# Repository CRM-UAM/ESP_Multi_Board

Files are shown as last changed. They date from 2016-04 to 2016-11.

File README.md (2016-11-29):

# ESP_Multi_Board (En constucción)
Diseño de una nueva placa basada en el módulo ESP8266 con conextividad WIFI y extensión para soportar dos motores DC, 8 GPIO digitales (MCP23008), 12 entradas Análogicas (MAX11605EEE+), giroscopio y acelerómetro (MPU6050)


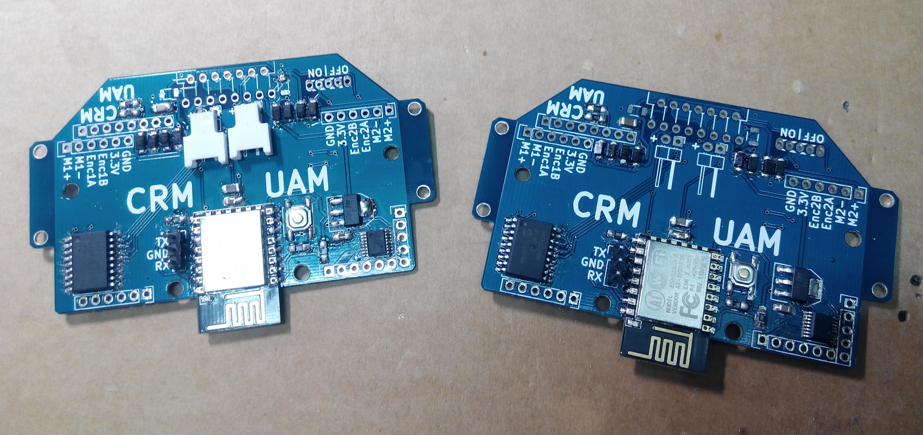
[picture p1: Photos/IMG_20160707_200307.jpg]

_ESP Multi Boards_

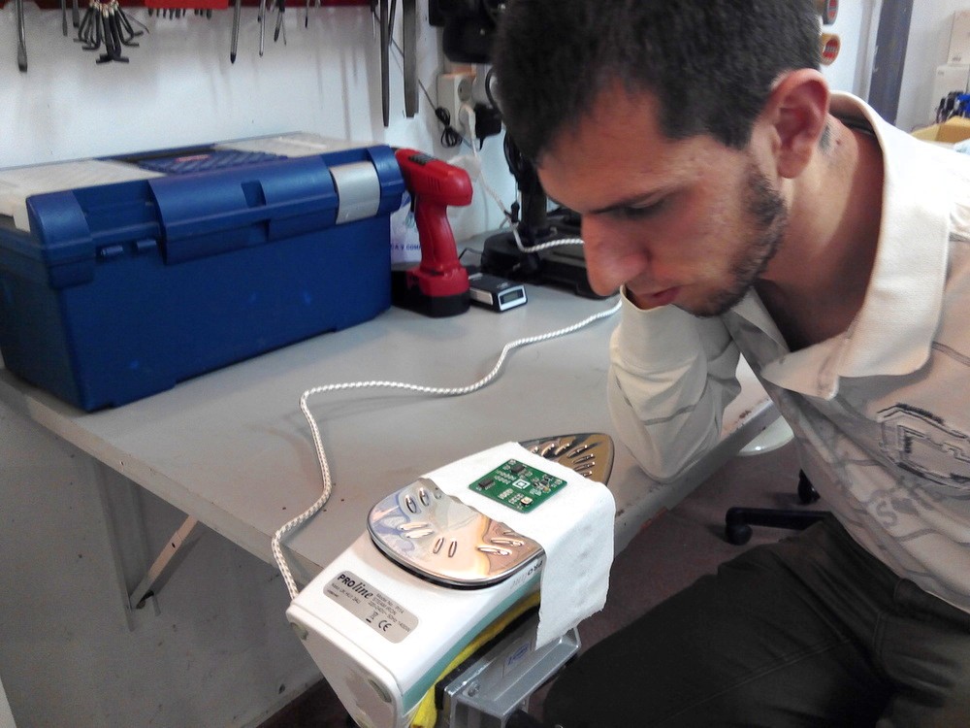
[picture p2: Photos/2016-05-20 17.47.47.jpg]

_SMD boards can be soldered using an iron and low-temp solder paste (a.k.a. "¡soldadas con [el método de la plancha!](https://www.youtube.com/watch?v=2VqYg4uM7OA)")_

##Librerias
+ [Arduino IDE for ESP8266](http://www.arduinesp.com/ "ArduinESP")
+ [MCP23008 lib for Arduino](https://github.com/adafruit/Adafruit-MCP23008-library "MCP23008 library")

IR values
cm - val
0 - 216
2 - 130
3 - 92
4 - 73
5 - 53
6 - 40
7 - 34
10 - 21

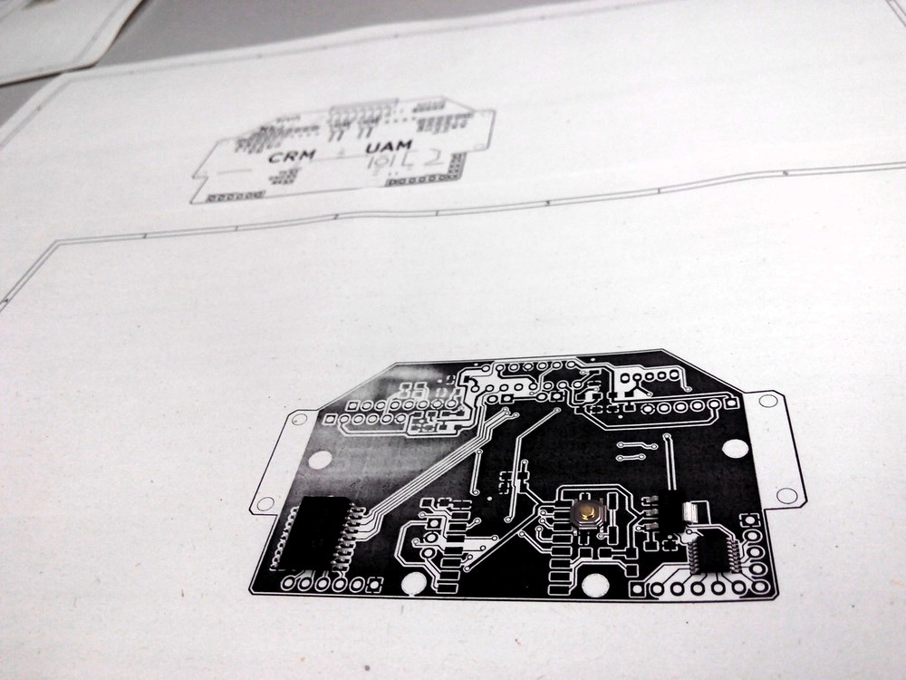
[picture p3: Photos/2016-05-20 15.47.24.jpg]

_Testing the components before sending the PCB out for manufacture_

Authors
--
**Víctor Uceda & Carlos García**  
Club de Robótica-Mecatrónica, Universidad Autónoma de Madrid (CRM-UAM)  
<http://crm.ii.uam.es>  

License
--
License: **Attribution - Share Alike - Creative Commons (<http://creativecommons.org/licenses/by-sa/4.0/>)**  

Disclaimer  
--
This hardware/software is provided "as is", and you use the hardware/software at your own risk. Under no circumstances shall any author be liable for direct, indirect, special, incidental, or consequential damages resulting from the use, misuse, or inability to use this hardware/software, even if the authors have been advised of the possibility of such damages.

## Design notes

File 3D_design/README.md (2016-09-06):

IR sensor holder for maze-solving with ESP-Multi-Board
=

Holds a *SFH4545* (photo-diode) infrared emmiter and a *TEFT4300* (photo-transistor) receiver

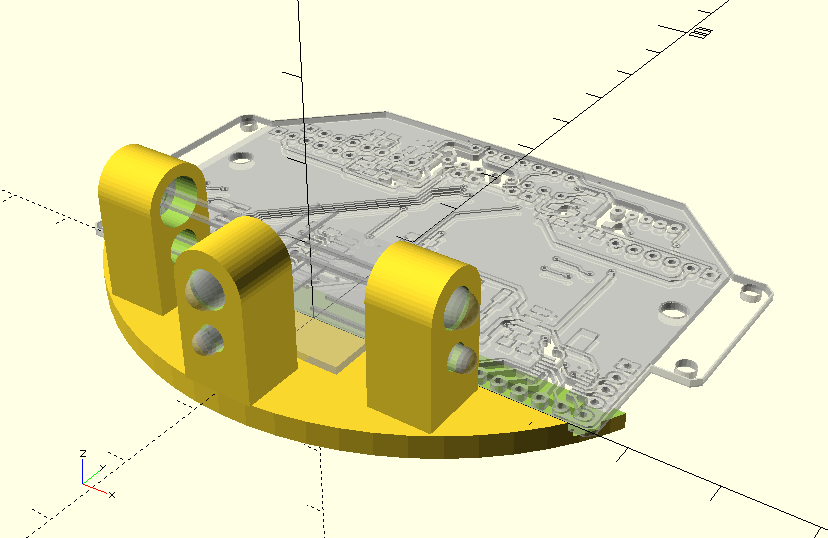
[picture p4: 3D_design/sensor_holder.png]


License: CC-BY-SA 4.0 (Attribution-ShareAlike 4.0 International, <http://creativecommons.org/licenses/by-sa/4.0/>)
Designed with <http://www.openscad.org/>

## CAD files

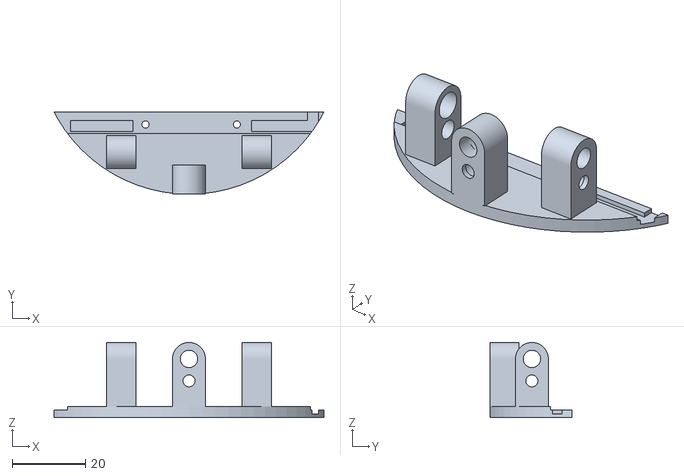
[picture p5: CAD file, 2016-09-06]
3D_design/sensor_holder.stl
73.7 x 22.5 x 20.5

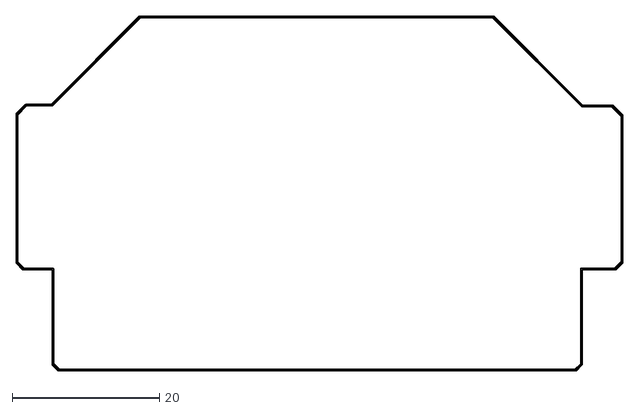
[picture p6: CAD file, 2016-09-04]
3D_design/ESP_multi_board-Edge.Cuts.dxf
82.3 x 48.1

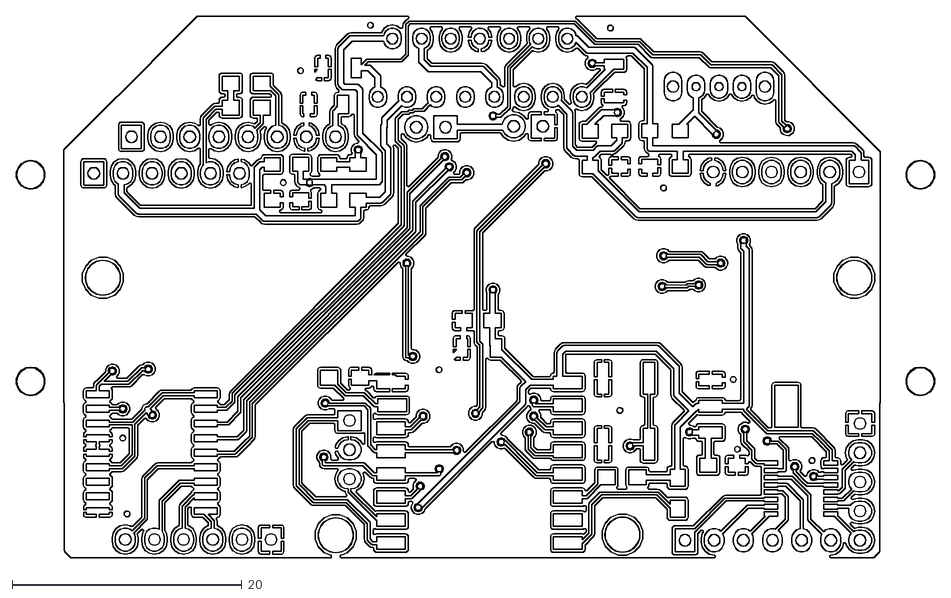
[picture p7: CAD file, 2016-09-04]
3D_design/ESP_multi_board-F.Cu.dxf
80.0 x 47.2

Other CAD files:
3D_design/sensor_holder.scad

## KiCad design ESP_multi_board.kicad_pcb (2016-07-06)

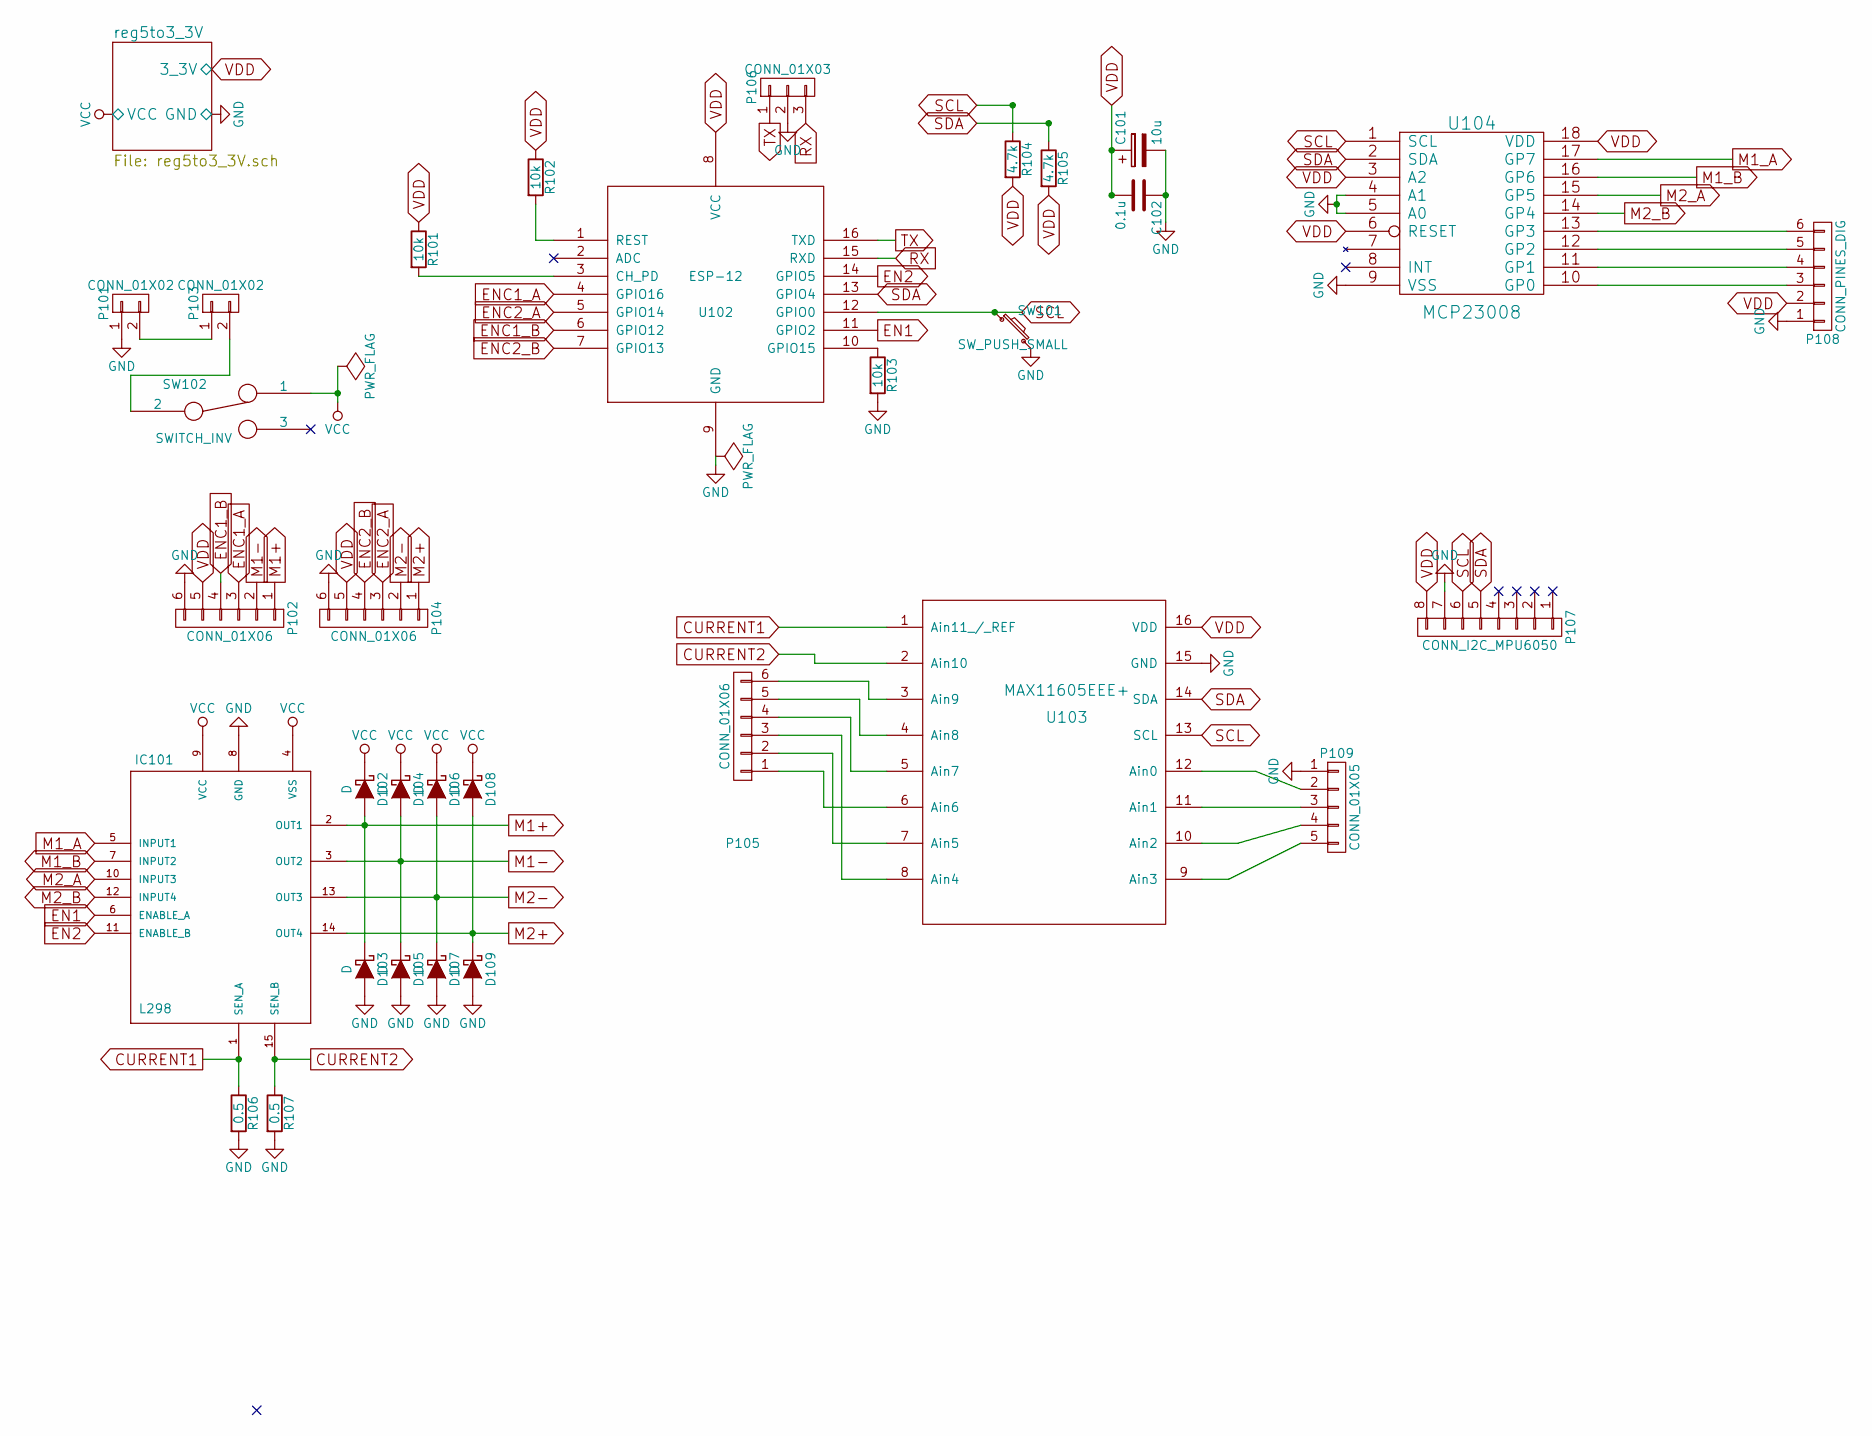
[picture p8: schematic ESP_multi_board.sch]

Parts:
C101: 10u; C_1206
C102: 0.1u; C_0805_HandSoldering
D102, D103, D104, D105, D106, D107, D108, D109: D; SMD_D_SMA-Sub-2
IC101: L298; Multiwatt_15_Vertical
P101, P103: CONN_01X02; Pin_Header_Angled_1x02
P102, P104, P105: CONN_01X06; Pin_Header_Straight_1x06
P106: CONN_01X03; Pin_Header_Straight_1x03
P107: CONN_I2C_MPU6050; Socket_Strip_Straight_1x08
P108: CONN_PINES_DIG; Pin_Header_Straight_1x06
P109: CONN_01X05; Pin_Header_Straight_1x05
R101, R102, R103: 10k; R_0805_HandSoldering
R104, R105: 4.7k; R_0805_HandSoldering
R106, R107: 0.5; R_1206
SW101: SW_PUSH_SMALL; SW_SPST_EVPBF
SW102: SWITCH_INV; switch_power_custom
U102: ESP-12
U103: MAX11605EEE+; SSOP-16_3.9x4.9mm_Pitch0.635mm
U104: MCP23008; SOIC-18_7.5x11.6mm_Pitch1.27mm

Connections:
CURRENT1: IC101.1 (SEN_A), R106.1, U103.1 (Ain11_/_REF)
CURRENT2: IC101.15 (SEN_B), R107.1, U103.2 (Ain10)
EN1: IC101.6 (ENABLE_A), U102.11 (GPIO2)
EN2: IC101.11 (ENABLE_B), U102.14 (GPIO5)
ENC1_A: P102.3, U102.4 (GPIO16)
ENC1_B: P102.4, U102.6 (GPIO12)
ENC2_A: P104.3, U102.5 (GPIO14)
ENC2_B: P104.4, U102.7 (GPIO13)
GND: C101.2, C102.1, D103.2 (A), D105.2 (A), D107.2 (A), D109.2 (A), IC101.8 (GND), P101.1, P102.6, P104.6, P106.2, P107.7, P108.1, P109.1, R103.2, R106.2, R107.2, SW101.2, U102.9 (GND), U103.15 (GND), U104.4 (A1), U104.5 (A0), U104.9 (VSS); also elsewhere on the board
M1+: D102.2 (A), D103.1 (K), IC101.2 (OUT1), P102.1
M1-: D104.2 (A), D105.1 (K), IC101.3 (OUT2), P102.2
M1_A: IC101.5 (INPUT1), U104.17 (GP7)
M1_B: IC101.7 (INPUT2), U104.16 (GP6)
M2+: D108.2 (A), D109.1 (K), IC101.14 (OUT4), P104.1
M2-: D106.2 (A), D107.1 (K), IC101.13 (OUT3), P104.2
M2_A: IC101.10 (INPUT3), U104.15 (GP5)
M2_B: IC101.12 (INPUT4), U104.14 (GP4)
unnamed: P101.2, P103.1
unnamed: P103.2, SW102.2
unnamed: P105.1, U103.6 (Ain6)
unnamed: P105.2, U103.7 (Ain5)
unnamed: P105.3, U103.8 (Ain4)
unnamed: P105.4, U103.5 (Ain7)
unnamed: P105.5, U103.4 (Ain8)
unnamed: P105.6, U103.3 (Ain9)
unnamed: P108.3, U104.10 (GP0)
unnamed: P108.4, U104.11 (GP1)
unnamed: P108.5, U104.12 (GP2)
unnamed: P108.6, U104.13 (GP3)
unnamed: P109.2, U103.12 (Ain0)
unnamed: P109.3, U103.11 (Ain1)
unnamed: P109.4, U103.10 (Ain2)
unnamed: P109.5, U103.9 (Ain3)
unnamed: R101.2, U102.3 (CH_PD)
unnamed: R102.2, U102.1 (REST)
unnamed: R103.1, U102.10 (GPIO15)
RX: P106.3, U102.15 (RXD)
SCL: P107.6, R104.1, SW101.1, U102.12 (GPIO0), U103.13 (SCL), U104.1 (SCL)
SDA: P107.5, R105.1, U102.13 (GPIO4), U103.14 (SDA), U104.2 (SDA)
TX: P106.1, U102.16 (TXD)
VCC: D102.1 (K), D104.1 (K), D106.1 (K), D108.1 (K), IC101.4 (VSS), IC101.9 (VCC), SW102.1; also elsewhere on the board
VDD: C101.1, C102.2, P102.5, P104.5, P107.8, P108.2, R101.1, R102.1, R104.2, R105.2, U102.8 (VCC), U103.16 (VDD), U104.3 (A2), U104.6 (RESET), U104.18 (VDD); also elsewhere on the board

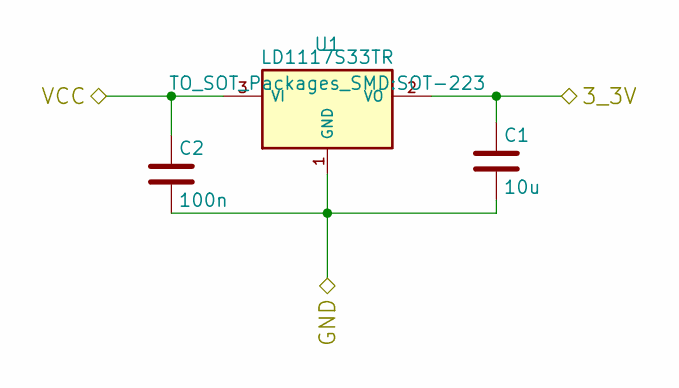
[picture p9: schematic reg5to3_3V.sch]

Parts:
C1: 10u; C_1206
C2: 100n; C_0805_HandSoldering
U1: LD1117S33TR; SOT-223

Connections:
GND: C1.2, C2.2, U1.1 (GND); also elsewhere on the board
VCC: C2.1, U1.3 (VI); also elsewhere on the board
VDD: C1.1, U1.2 (VO); also elsewhere on the board

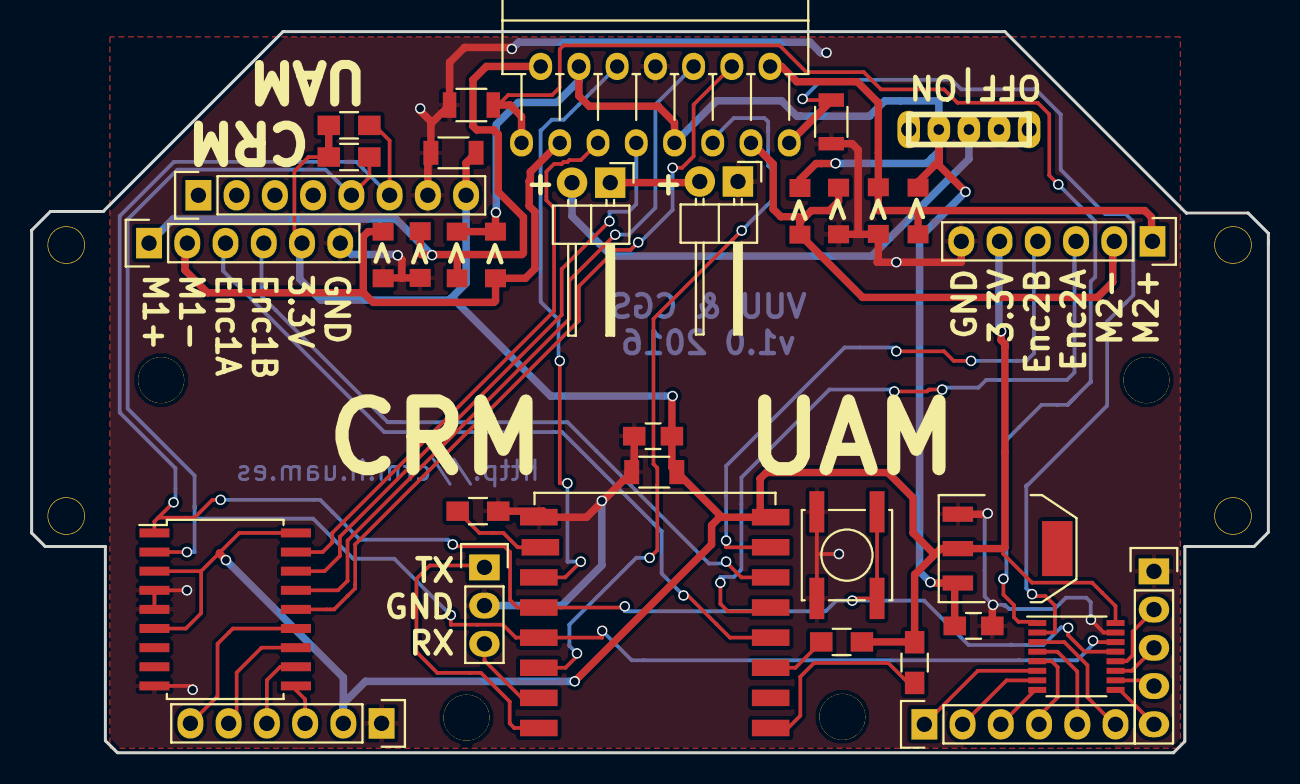
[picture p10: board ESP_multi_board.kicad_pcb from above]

Board: 2 copper layers, 82.1 x 47.9 mm, 45 parts (0 on the bottom side), 42 nets.

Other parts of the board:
drill3, drill4, drill7, drill8, drill8#2, drill8#3, drill9, drill11, drill14, drill20: 1pin

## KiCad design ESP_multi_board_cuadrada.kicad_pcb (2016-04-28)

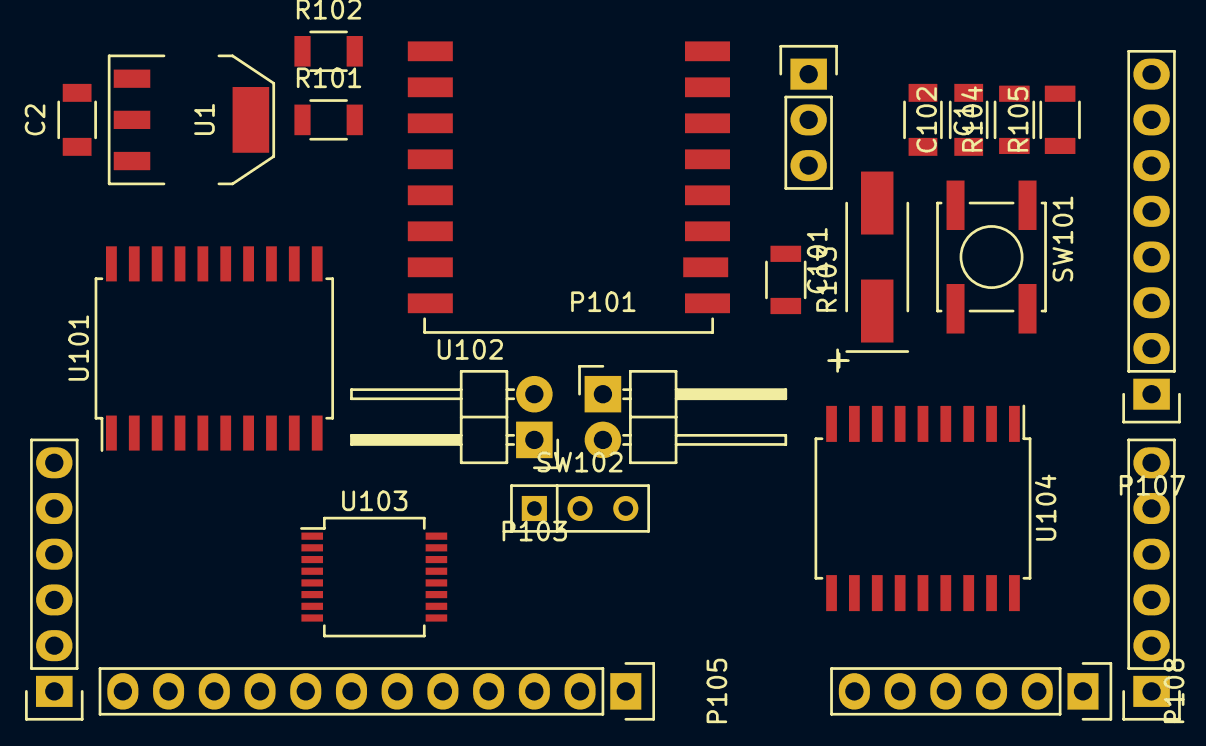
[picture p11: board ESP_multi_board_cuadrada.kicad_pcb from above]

Board: 2 copper layers, 24 parts (0 on the bottom side), 42 nets.

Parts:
C1: 10u; C_1206
C2: 100n; C_1206
C101: 10u; TantalC_SizeC_EIA-6032_HandSoldering
C102: 0.1u; C_1206
P101, P103: CONN_01X02; Pin_Header_Angled_1x02
P102, P104: CONN_01X06; Pin_Header_Straight_1x06
P105: CONN_01X12; Pin_Header_Straight_1x12
P106: CONN_01X03; Pin_Header_Straight_1x03
P107: CONN_I2C_MPU6050; Pin_Header_Straight_1x08
P108: CONN_PINES_DIG; Pin_Header_Straight_1x06
R101, R102, R103: 10k; R_1206
R104, R105: 47k; R_1206
SW101: SW_PUSH_SMALL; SW_SPST_EVPBF
SW102: SWITCH_INV; SW_Micro_SPST
U1: LD1117S33TR; SOT-223
U101: L293DD; SOIC-20_7.5x12.8mm_Pitch1.27mm
U102: ESP-12
U103: MAX11605EEE+; SSOP-16_5.3x6.2mm_Pitch0.65mm
U104: MCP23008; SOIC-18_7.5x11.6mm_Pitch1.27mm

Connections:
EN1: U101.1, U102.11
EN2: U101.11, U102.14
ENC1_A: P102.5, U102.4
ENC1_B: P102.6, U102.6
ENC2_A: P104.5, U102.5
ENC2_B: P104.6, U102.7
GND: C1.2, C2.2, C101.2, C102.1, P101.1, P102.4, P104.4, P106.2, P107.2, P107.7, P108.1, R103.2, SW101.2, U1.1, U101.4, U101.5, U101.6, U101.7, U101.14, U101.15, U101.16, U101.17, U102.9, U103.15, U104.4, U104.5, U104.9
M1+: P102.1, U101.3
M1-: P102.2, U101.8
M1_A: U101.2, U104.10
M1_B: U101.9, U104.11
M2+: P104.1, U101.18
M2-: P104.2, U101.13
M2_A: U101.19, U104.12
M2_B: U101.12, U104.13
unnamed: P101.2, SW102.2
unnamed: P103.1, SW102.1
unnamed: P105.1, U103.12
unnamed: P105.2, U103.11
unnamed: P105.3, U103.10
unnamed: P105.4, U103.9
unnamed: P105.5, U103.6
unnamed: P105.6, U103.7
unnamed: P105.7, U103.8
unnamed: P105.8, U103.5
unnamed: P105.9, U103.4
unnamed: P105.10, U103.3
unnamed: P105.11, U103.2
unnamed: P105.12, U103.1
unnamed: P108.3, U104.17
unnamed: P108.4, U104.16
unnamed: P108.5, U104.15
unnamed: P108.6, U104.14
unnamed: R101.2, U102.3
unnamed: R102.2, U102.1
unnamed: R103.1, U102.10
RX: P106.3, U102.15
SCL: P107.6, R104.1, SW101.1, U102.12, U103.13, U104.1
SDA: P107.5, R105.1, U102.13, U103.14, U104.2
TX: P106.1, U102.16
VCC: C2.1, P103.2, U1.3, U101.10
VDD: C1.1, C101.1, C102.2, P102.3, P104.3, P107.8, P108.2, R101.1, R102.1, R104.2, R105.2, U1.2, U101.20, U102.8, U103.16, U104.3, U104.6, U104.18

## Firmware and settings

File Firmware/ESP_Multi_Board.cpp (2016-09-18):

/***************************************************
  This is a library for the ESP_Multi_Board

  Written by Victor Uceda for Club de Robotica of Universidad Autonoma de Madrid (CRM-UAM).
 ****************************************************/

#if ARDUINO >= 100
 #include "Arduino.h"
#else
 #include "WProgram.h"
#endif
#include "ESP_Multi_Board.h"

#include <Wire.h>
#include <pgmspace.h>

#include "Adafruit_MCP23008.h"
#include "I2Cdev.h"
#include "MPU6050.h"


extern "C" {
    #include "user_interface.h"
}

Adafruit_MCP23008 mcp;
//MPU6050 accelgyro;


volatile long count_enc_r;
volatile long count_enc_l;
//Encoder read idea: http://makeatronics.blogspot.com.es/2013/02/efficiently-reading-quadrature-with.html
void changeEnc1(){

    static int8_t lookup_table[] = {0,0,0,-1,0,0,1,0,0,1,0,0,-1,0,0,0};
    static uint8_t enc1_val = 0;

    uint8_t v = (digitalRead(ENC_1_A)<<1) | digitalRead(ENC_1_B);

    enc1_val = enc1_val << 2;
    enc1_val = enc1_val | (v & 0b11);

    count_enc_r = count_enc_r - lookup_table[enc1_val & 0b1111];
}

//Encoder read idea: http://makeatronics.blogspot.com.es/2013/02/efficiently-reading-quadrature-with.html
void changeEnc2(){

    static int8_t lookup_table[] = {0,0,0,-1,0,0,1,0,0,1,0,0,-1,0,0,0};
    static uint8_t enc2_val = 0;

    uint8_t v = (digitalRead(ENC_2_A)<<1) | digitalRead(ENC_2_B);

    enc2_val = enc2_val << 2;
    enc2_val = enc2_val | (v & 0b11);

    count_enc_l = count_enc_l + lookup_table[enc2_val & 0b1111];
}


void ESP_Multi_Board::pinMode(uint8_t p, uint8_t d) {
    if(p<4)
        mcp.pinMode(p,d);
}

uint8_t ESP_Multi_Board::readGPIO(void) {
  return mcp.readGPIO();
}

void ESP_Multi_Board::writeGPIO(uint8_t gpio) {
  mcp.writeGPIO(gpio);
}


void ESP_Multi_Board::digitalWrite(uint8_t p, uint8_t d) {
  if(p<4)
    mcp.digitalWrite(p,d);
}

void ESP_Multi_Board::pullUp(uint8_t p, uint8_t d) {
    if(p<4)
        mcp.pullUp(p,d);
}

uint8_t ESP_Multi_Board::digitalRead(uint8_t p) {
 return mcp.digitalRead(p);
}


uint8_t ESP_Multi_Board::analogRead(uint8_t p){
    if(p>11)return 0;

  Wire.beginTransmission(MAX1605_ADDRESS); //init with slave adress
  uint8_t conf = 0 ;
  conf ^= p<<1; //toggle pin number in bits 4º, 3º, 2º, 1º
  conf |= 0x61; //set scan1=1, scan0=1 (simple read mode). set bit single-ended to 1
  //Serial.print("(");printBits(conf);Serial.print(")");
  Wire.write((byte)conf);
  Wire.endTransmission();

  Wire.requestFrom(MAX1605_ADDRESS, 1);
  return Wire.read();
}

uint8_t ESP_Multi_Board::analogScand(uint8_t size, uint8_t *table){
    if(size>11)return 0;

  Wire.beginTransmission(MAX1605_ADDRESS); //init with slave adress
  uint8_t conf = 0 ;
  conf ^= size<<1; //toggle pin number in bits 4º, 3º, 2º, 1º
  conf |= 0x01; //set scan1=0, scan0=0 (scand mode). set bit single-ended to 1
  //Serial.print("(");printBits(conf);Serial.print(")");
  Wire.write((byte)conf);
  Wire.endTransmission();

  Wire.requestFrom(MAX1605_ADDRESS, size);
  for(uint8_t i=0;i<size;i++){
    table[i]=Wire.read();
  }
  return size;
}


void ESP_Multi_Board::setMotorLeftSpeed(int velL){
    if(velL < 0){
        mcp.digitalWrite(5,HIGH);
        mcp.digitalWrite(4,LOW);
        velL=-velL;
    }else{
        mcp.digitalWrite(5,LOW);
        mcp.digitalWrite(4,HIGH);
    }
    if(velL > 1024) velL=1024;
    /*if(velL <= 20){
        velL = map(velL,0,20, 0, 50);
    }else{
        velL = map(velL,21,1023, 50, 1023);
    }*/
    analogWrite(5, velL); //set motor A high speed
}

void ESP_Multi_Board::setMotorRightSpeed(int velR){
    if(velR < 0){
        mcp.digitalWrite(7,HIGH);
        mcp.digitalWrite(6,LOW);
        velR=-velR;
    }else{
        mcp.digitalWrite(7,LOW);
        mcp.digitalWrite(6,HIGH);
    }
    if(velR > 1024) velR=1024;

    /*if(velR <= 20){
        velR = map(velR,0,20, 0, 50);
    }else{
        velR = map(velR,21,1023, 50, 1023);
    }*/
    analogWrite(2, velR); //set motor A high speed
}

void ESP_Multi_Board::setSpeed(int velL, int velR){
    setMotorLeftSpeed(velL);
    setMotorRightSpeed(velR);
}

uint8_t ESP_Multi_Board::getMotorLeftCurrent(){
    return ESP_Multi_Board::analogRead(11);
}

uint8_t ESP_Multi_Board::getMotorRightCurrent(){
    return ESP_Multi_Board::analogRead(10);
}

long ESP_Multi_Board::getEncRightCount(){
    return count_enc_r;
}

long ESP_Multi_Board::getEncLeftCount(){
    return count_enc_l;
}

void ESP_Multi_Board::resetEncRight(){
    count_enc_r=0;
}

void ESP_Multi_Board::resetEncLeft(){
    count_enc_l=0;
}

void ESP_Multi_Board::resetEncoders(){
    count_enc_r=0;
    count_enc_l=0;
}




const int MPU = 0x68; // I2C address of the MPU-6050

#define MPU6050_PWR_MGMT_1    0x6B
#define MPU6050_ACCEL_CONFIG  0x1C
#define MPU6050_GYRO_CONFIG   0x1B
#define MPU6050_SMPLRT_DIV    0x19
#define MPU6050_CONFIG        0x1A

int16_t AcX, AcY, GyZ;
int16_t AcX_raw, AcY_raw, GyZ_raw;
int16_t AcXoffset, AcYoffset, GyZoffset;
float GyZ_integral, rotation;
unsigned long IMU_last_ts = 0;
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

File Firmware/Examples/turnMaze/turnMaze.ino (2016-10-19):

#if ARDUINO >= 100
 #include "Arduino.h"
#else
 #include "WProgram.h"
#endif

#include <Wire.h>
#include <pgmspace.h>
#include <ESP8266WiFi.h>
#include <ESP_Multi_Board.h>

extern "C" {
#include "user_interface.h"
}

//const char* ssid = "ONOFBA9";
//const char* password = "4125905522uceda";
const char* ssid = "wifiVictor";
const char* password = "wifivictor";



WiFiServer server(23);
WiFiClient serverClient;

ESP_Multi_Board robot;
os_timer_t timerSpeedController;


#define SIZE_TELEMETRIA 120//40*30 30seg telemetry
#define DIM_TELEMETRIA 8
float telemetria[SIZE_TELEMETRIA+1][DIM_TELEMETRIA]={0};
int p_telemetria=0;

//call speedProfile(void) in systick handle to make it execute every one milli second
//this controller sample code doesn't include

//here are the code you need to call periodically to make the mouse sample and excute and a constant rate
//in order to make sample and pwm updating at a constant rate, you'd better call the code in the handler of a timer periodically
//the period for intterupt handler is usually 1ms, which means you have to finish all code excuting within 1ms
//I simply call the controller code in systick handler that intterupts every 1ms, notice systick timer is also used to
//keep track the system time in millisecond
/*
//test the timing make sure everything finishes within 1ms and leave at least 30% extra time for other code to excute in main routing
void systickHandler(void)
{
    Millis++;  //keep track of the system time in millisecond
    if(bUseIRSensor)
        readIRSensor();
    if(bUseGyro)
        readGyro();
    if(bUseSpeedProfile)
        speedProfile
}
*/

//ps. if you want to change speed, you simply change the targetSpeedX and targetSpeedW in main routing(int main) at any time.



long distanceLeft=0;
float curSpeedX = 0;
float curSpeedW = 0;
int targetSpeedX = 0;
int targetSpeedW = 0;
int encoderFeedbackX = 0;
int encoderFeedbackW = 0;
float pidInputX = 0;
float pidInputW = 0;
float posErrorX = 0;
float posErrorW = 0;
float posErrorWir = 0;
float oldPosErrorX = 0;
float oldPosErrorW = 0;
float oldPosErrorWir = 0;
int posPwmX = 0;
int posPwmW = 0;
int posPwmWir = 0;

#define TARGET_WALL_DIST 70
float IR_WEIGHT = 0.0;
const float ir_weight_straight = 1.0;
const float ENCODER_GYRO_WEIGHT = 1.0;

float kpX = 0.95, kdX = 10;
float kpW = 0.8, kdW = 17;//used in straight
const float kpW0 = kpW, kdW0 = kdW;//used in straight
float kpWir = 0.6, kdWir = 6.5;//used with IR errors
const float kpW1 = 0.85, kdW1 = 16;//used for T1 and T3 in curve turn
const float kpW2 = 0.8, kdW2 = 20;//used for T2 in curve turn

float accX = 45;//6m/s/s
float decX = 35;
float accW = 1; //cm/s^2
float decW = 1;

long encoderCount=0;
long encoderChange=0;
long oldEncoderCount=0;
long leftEncoderChange=0;
long rightEncoderChange=0;
long leftEncoderOld = 0;
long rightEncoderOld = 0;
long leftEncoder = 0;
long  rightEncoder = 0;
long leftEncoderCount = 0;
long rightEncoderCount = 0;
    
int leftBaseSpeed = 0;
int rightBaseSpeed = 0;

#define R_WHEEL 15.65 //radius in mm
#define ONE_CELL_DISTANCE 27500/(2*3.14*R_WHEEL)
#define speed_to_counts(a) (120*(a)/(2*3.14*R_WHEEL))
#define counts_to_speed(a) ((a)*(2*3.14*R_WHEEL)/120)
//#define abs(x)  (x<0)?(-x):(x)

//speed to count or count to speed are the macro or function to make the unit conversion
// between encoder_counts/ms and mm/ms or any practical units you use.
int moveSpeed = speed_to_counts(0);
int turnSpeed = speed_to_counts(12);
int returnSpeed = speed_to_counts(500*2);
int stopSpeed = speed_to_counts(100*2);
int maxSpeed = speed_to_counts(15);


float gyroFeedbackRatio = -223.5;//5900;

void getEncoderStatus()
{
    long leftEncoder = robot.getEncLeftCount(); //leftEncoder = TIM2->CNT;//read current encoder ticks from register of 32 bit general purpose timer 2
    long rightEncoder = robot.getEncRightCount(); //rightEncoder = TIM5->CNT;//read current encoder ticks from register of 32 bit general purpose timer 5



    leftEncoderChange = leftEncoder - leftEncoderOld;
    rightEncoderChange = rightEncoder - rightEncoderOld;
    encoderChange = (leftEncoderChange + rightEncoderChange)/2;

    leftEncoderOld = leftEncoder;
    rightEncoderOld = rightEncoder;

    leftEncoderCount += leftEncoderChange;
    rightEncoderCount += rightEncoderChange;
    encoderCount =  (leftEncoderCount+rightEncoderCount)/2;

    distanceLeft -= encoderChange;// update distanceLeft
}



void updateCurrentSpeed(void)
{
    if(curSpeedX < targetSpeedX && curSpeedX >= 0){
        curSpeedX += (float)(speed_to_counts(accX*2)/100);
        if(curSpeedX > targetSpeedX)
            curSpeedX = targetSpeedX;
    }else if(curSpeedX > targetSpeedX && curSpeedX > 0){
        curSpeedX -= (float)speed_to_counts(decX*2)/100;
        if(curSpeedX < targetSpeedX)
            curSpeedX = targetSpeedX;
    }else if(curSpeedX < targetSpeedX && curSpeedX < 0){
        curSpeedX += (float)speed_to_counts(decX*2)/100;
        if(curSpeedX > targetSpeedX)
            curSpeedX = targetSpeedX;
    }else if(curSpeedX > targetSpeedX && targetSpeedX <= 0){
        curSpeedX -= (float)(speed_to_counts(accX*2)/100);
        if(curSpeedX < targetSpeedX)
            curSpeedX = targetSpeedX;
    }
    
    if(curSpeedW < targetSpeedW && curSpeedW >= 0){
        curSpeedW += accW;
        if(curSpeedW > targetSpeedW)
            curSpeedW = targetSpeedW;
    }else if(curSpeedW > targetSpeedW && curSpeedW > 0){
        curSpeedW -= decW;
        if(curSpeedW < targetSpeedW)
            curSpeedW = targetSpeedW;
    }else if(curSpeedW < targetSpeedW && curSpeedW < 0){
        curSpeedW += decW;
        if(curSpeedW > targetSpeedW)
            curSpeedW = targetSpeedW;
    }else if(curSpeedW > targetSpeedW && curSpeedW <= 0){
        curSpeedW -= accW;
        if(curSpeedW < targetSpeedW)
            curSpeedW = targetSpeedW;
    }
    
}

void leerIRs(uint8_t *data){
  uint8_t IR_value1[3]={0};
  uint8_t IR_value2[3]={0};
  robot.analogScand(3, IR_value1);  
  robot.digitalWrite(0,HIGH);
  robot.analogScand(3, IR_value2);
  robot.digitalWrite(0,LOW);
  for(int i=0;i<3;i++){
    data[i] = (IR_value2[i] - IR_value1[i]);
  }
}
inline void getErrIRNew(){
  int DLMiddleValue=101;
  int DRMiddleValue=170;
    int DLMinValue=60;
    int DRMinValue=76;
    uint8_t IR_value[3]={0};
    leerIRs(IR_value);
    telemetria[p_telemetria][6]=IR_value[0];
    telemetria[p_telemetria][7]=IR_value[2];

    if( abs(DLMiddleValue - IR_value[0]) < abs(IR_value[2] - DRMiddleValue) ){ //pared izqueirda mas cercana que la derecha, la utilizo para ir por el centro
      if(IR_value[0] > DLMinValue) //pared detectada por encima del umbral minimo 
        posErrorWir = DLMiddleValue - IR_value[0];
      else //pared no detectada
        posErrorWir /= 3; 
    }else{
      if(IR_value[2] > DRMinValue )
        posErrorWir = IR_value[2] - DRMiddleValue;
      else
        posErrorWir /= 3;
    }
}

inline void getErrIRChino(){
      int DLMiddleValue=101;
    int DRMiddleValue=170;
    int DLMinValue=60;
    int DRMinValue=76;
    
    uint8_t IR_value[3]={0};
    leerIRs(IR_value);
    
    telemetria[p_telemetria][6]=IR_value[0];
    telemetria[p_telemetria][7]=IR_value[2];

    if(IR_value[0] > DLMinValue || IR_value[2] > DRMinValue){
      if(IR_value[0] > IR_value[2]){
        posErrorWir = DLMiddleValue - IR_value[0];
      }else{
        posErrorWir = IR_value[2] - DRMiddleValue;
      }
      
    }else{
      posErrorWir=0;
    }
}

inline void getErrIR(){
    int DLMiddleValue=101;
    int DRMiddleValue=170;
    int DLMinValue=60;
    int DRMinValue=76;
    
    uint8_t IR_value[3]={0};
    leerIRs(IR_value);
    
    telemetria[p_telemetria][6]=IR_value[0];
    telemetria[p_telemetria][7]=IR_value[2];
    
    if(IR_value[0] > DLMinValue && IR_value[2] < DRMinValue){
      posErrorWir = DLMiddleValue - IR_value[0];
      if(IR_value[0] < DLMiddleValue)
        posErrorWir /=3;
    }else if(IR_value[2] > DRMinValue && IR_value[0] < DLMinValue){
      posErrorWir = IR_value[2] - DRMiddleValue;
      if(IR_value[2] < DRMiddleValue)
        posErrorWir /=3;
    }else if(IR_value[0] > DLMinValue && IR_value[2] > DRMinValue){
      posErrorWir = 0;
      
      if(IR_value[0] < DLMiddleValue)
        posErrorWir += (DLMiddleValue - IR_value[0])/3;
      else 
        posErrorWir += (DLMiddleValue - IR_value[0]);
      
      if(IR_value[2] < DRMiddleValue)
        posErrorWir += (IR_value[2] - DRMiddleValue)/3;
      else
        posErrorWir += (IR_value[2] - DRMiddleValue);
        
      posErrorWir /= 2;
      
    }else
      posErrorWir /= 3;
}

void calculateMotorPwm(void) // encoder PD controller
{
    int sensorFeedback;
    
    //Serial.println(IR_value[0]);
    /* simple PD loop to generate base speed for both motors */
    encoderFeedbackX = rightEncoderChange + leftEncoderChange;
    encoderFeedbackW = rightEncoderChange - leftEncoderChange;
    float gyro = robot.read_IMU_GyZ()*1.0;
    float gyroFeedback = gyro / gyroFeedbackRatio; //gyroFeedbackRatio mentioned in curve turn lecture
    //gyroIntegrate += gyroFeedback;
    //sensorFeedback = sensorError/a_scale;//have sensor error properly scale to fit the system

    //if(onlyUseGyroFeedback)
    //    rotationalFeedback = gyroFeedback;
    //else if(onlyUseEncoderFeedback)
          float rotationalFeedback = /*((float)(ENCODER_GYRO_WEIGHT*1.0f)*(encoderFeedbackW*1.0f)) + ((float)(1.0f - ENCODER_GYRO_WEIGHT*1.0)*(*/gyroFeedback;//));
    //else
    //    rotationalFeedback = encoderFeedbackW + gyroFeedback;
        //if you use IR sensor as well, the line above will be rotationalFeedback = encoderFeedbackW + gyroFeedback + sensorFeedback;
        //make sure to check the sign of sensor error.
  
    posErrorX += curSpeedX - encoderFeedbackX;
    posErrorW += curSpeedW - rotationalFeedback;
   


    getErrIRChino();
    /*if(posErrorWir < 20){
      posErrorW = 0;
    }*/
     



    
    posPwmX = kpX * posErrorX + kdX * (posErrorX - oldPosErrorX);
    posPwmW = kpW * posErrorW + kdW * (posErrorW - oldPosErrorW);
    posPwmWir = kpWir * posErrorWir + kdWir * (posErrorWir - oldPosErrorWir); 

    oldPosErrorX = posErrorX;
    oldPosErrorW = posErrorW;
    oldPosErrorWir = posErrorWir;

    leftBaseSpeed = posPwmX - ( (1-IR_WEIGHT)*posPwmW + IR_WEIGHT*posPwmWir);
    rightBaseSpeed = posPwmX + ( (1-IR_WEIGHT)*posPwmW + IR_WEIGHT*posPwmWir);

    robot.setMotorLeftSpeed(leftBaseSpeed);
    robot.setMotorRightSpeed(rightBaseSpeed);
    if(p_telemetria<SIZE_TELEMETRIA){
      telemetria[p_telemetria][0]=micros();
      telemetria[p_telemetria][1]=curSpeedX;
      telemetria[p_telemetria][2]=encoderFeedbackX;
      //telemetria[p_telemetria][3]=curSpeedW;
      telemetria[p_telemetria][3]=curSpeedW;
      telemetria[p_telemetria][4]=rotationalFeedback;
      telemetria[p_telemetria][5]=posErrorWir;
      //telemetria[p_telemetria][6]=leftEncoderChange;
      p_telemetria++;
    }
    
}


float needToDecelerate(long dist, int curSpd, int endSpd)//speed are in encoder counts/ms, dist is in encoder counts
{
    if (curSpd<0) curSpd = -curSpd;
    if (endSpd<0) endSpd = -endSpd;
    if (dist<0) dist = 1;//-dist;
    if (dist == 0) dist = 1;  //prevent divide by 0

    return (abs(counts_to_speed((curSpd*curSpd - endSpd*endSpd)*100/(double)dist/4/2))); //dist_counts_to_mm(dist)/2);
    //calculate deceleration rate needed with input distance, input current speed and input targetspeed to determind if the deceleration is needed
    //use equation 2*a*S = Vt^2 - V0^2  ==>  a = (Vt^2-V0^2)/2/S
    //because the speed is the sum of left and right wheels(which means it's doubled), that's why there is a "/4" in equation since the square of 2 is 4
}

void resetSpeedProfile(void)
{
    //resetEverything;
    //disable sensor data collecting functions running in 1ms interrupt
//    useSensor = false;
//    useGyro = false;
    //no PID calculating, no motor lock
//    usePID = false;

    robot.setSpeed(0,0);//setLeftPwm(0);//setRightPwm(0);

    pidInputX = 0;
    pidInputW = 0;
    curSpeedX = 0;
    curSpeedW = 0;
    targetSpeedX = 0;
    targetSpeedW = 0;
    posErrorX = 0;
    posErrorW = 0;
    oldPosErrorX = 0;
    oldPosErrorW = 0;
    leftEncoderOld = 0;
    rightEncoderOld = 0;
    leftEncoder = 0;
    rightEncoder = 0;
    leftEncoderCount = 0;
    rightEncoderCount = 0;
    encoderCount = 0;
    oldEncoderCount = 0;
    leftBaseSpeed = 0;
    rightBaseSpeed = 0;

    robot.resetEncoders();//TIM2->CNT = 0;//reset left encoder count //TIM5->CNT = 0;//reset right encoder count
}

void speedProfile(void *a){ 
    getEncoderStatus(); 
    updateCurrentSpeed(); 
    calculateMotorPwm(); 
}

/*void getSensorEror(void)//the very basic case
{
    if(DLSensor > DLMiddleValue && DRSensor < DRMiddleValue)
        sensorError = DLMiddleValue - DLSensor;
    else if(DRSensor > DRMiddleValue && DLSensor < DLMiddleValue)
        sensorError = DRSensor - DRMiddleValue;
    else
        sensorError = 0;
}*/


/*
sample code for straight movement
*/
void moveOneCell()
{
    targetSpeedW = 0;
    targetSpeedX = moveSpeed;
    kpW = kpW0;
    kdW = kdW0;
    IR_WEIGHT = ir_weight_straight; // usar los IR para alinearte con la pared
    do
    {
        /*you can call int needToDecelerate(int32_t dist, int16_t curSpd, int16_t endSpd)
        here with current speed and distanceLeft to decide if you should start to decelerate or not.*/
        /*sample*/
        float accMin = needToDecelerate(ONE_CELL_DISTANCE-(encoderCount-oldEncoderCount), curSpeedX, moveSpeed);
        
        if( accMin < decX)
            targetSpeedX = maxSpeed;
        else
            targetSpeedX = moveSpeed;
            
        Serial.print(millis());Serial.print(" ");
        Serial.print(ONE_CELL_DISTANCE-(encoderCount-oldEncoderCount));Serial.print(" ");
        Serial.print(curSpeedX);Serial.print(" ");
        Serial.print(moveSpeed);Serial.print(" ");
        Serial.print(accMin);Serial.print(" ");
        Serial.print(decX);Serial.print(" ");
        Serial.print(targetSpeedX);Serial.println(" ");
        delay(5);
        //there is something else you can add here. Such as detecting falling edge of post to correct longitudinal position of mouse when running in a straight path
        //Serial.print(targetSpeedX);Serial.print(" ");Serial.print((encoderCount-oldEncoderCount));Serial.print(" ");Serial.print(ONE_CELL_DISTANCE);Serial.println("");
     }
    while( ( (encoderCount-oldEncoderCount) < ONE_CELL_DISTANCE )//&& LFSensor < LFvalue2 && RFSensor < RFvalue2)//use encoder to finish 180mm movement if no front walls
    //|| (LFSensor < LFvalues1 && LFSensor > LFvalue2)//if has front wall, make the mouse finish this 180mm with sensor threshold only
    //|| (RFSensor < RFvalue1 && RFSensor > RFvalve2)
    );
    //LFvalues1 and RFvalues1 are the front wall sensor threshold when the center of mouse between the boundary of the cells.
    //LFvalues2 and RFvalues2 are the front wall sensor threshold when the center of the mouse staying half cell farther than LFvalues1 and 2
    //and LF/RFvalues2 are usually the threshold to determine if there is a front wall or not. You should probably move this 10mm closer to front wall when collecting
    //these thresholds just in case the readings are too weak.

    Serial.print("Final Encoder Count");Serial.println((encoderCount-oldEncoderCount));
    oldEncoderCount = encoderCount; //update here for next movement to minimized the counts loss between cells.
}

void turn90(int dir){
  float velW=7.4*dir;
  long t1 = (speed_to_counts(abs(velW))/accW)*25;
  long t2 = 510;
  long t3 = (speed_to_counts(abs(velW))/decW)*25;
  long tini = millis();
  IR_WEIGHT = 0; //no usar los IR para alinearte con la pared cuando estas girando
  targetSpeedX = turnSpeed;
  targetSpeedW = speed_to_counts(velW);
  kpW = kpW1;
  kdW = kdW1;
  while(millis()-tini < t1){delay(1);}
  tini = millis();
  kpW = kpW2;
  kdW = kdW2;
  while(millis()-tini < t2){delay(1);}
  tini = millis();
  kpW = kpW1;
  kdW = kdW1;
  targetSpeedW = 0;
  targetSpeedX = targetSpeedX/4;
  while(millis()-tini < t3){delay(1);}
  targetSpeedX = 0;
  kpW = kpW0;
  kdW = kdW0;
  oldEncoderCount = encoderCount;
}

void turn180(int dir){
  float velW=16*dir;
  long t1 = (speed_to_counts(abs(velW))/accW)*25;
  long t2 =310;
  long t3 = (speed_to_counts(abs(velW))/decW)*25;
  long tini = millis();
  IR_WEIGHT = 0; //no usar los IR para alinearte con la pared cuando estas girando
  targetSpeedX = 0;
  targetSpeedW = speed_to_counts(velW);
  kpW = kpW1;
  kdW = kdW1;
  while(millis()-tini < t1){delay(1);}
  tini = millis();
  kpW = kpW2;
  kdW = kdW2;
  while(millis()-tini < t2){delay(1);}
  tini = millis();
  kpW = kpW1;
  kdW = kdW1;
  targetSpeedW = 0;
  targetSpeedX = 0;
  while(millis()-tini < t3){delay(1);}
  targetSpeedX = 0;
  kpW = kpW0;
  kdW = kdW0;
  oldEncoderCount = encoderCount;
}


void init_telnet(){
  WiFi.begin(ssid, password);
  Serial.print("\nConnecting to "); Serial.println(ssid);
  while (WiFi.status() != WL_CONNECTED){
    delay(500);
    Serial.print(".");
  }
  server.begin();
  server.setNoDelay(true);
  Serial.print("\nReady! Use 'telnet ");
  Serial.print(WiFi.localIP());
  Serial.println(" 23' to connect");
}

void print_tl(String str){
  if (serverClient && serverClient.connected()){
        serverClient.print(str);
   }
}

void check_send_telnet_telemetry(){
  if (server.hasClient()){
    if (!serverClient || !serverClient.connected()){
        if(serverClient) serverClient.stop();
        serverClient = server.available();
        Serial.println("New client: ");
      }
  }

  //check clients for data
  /*if (serverClient && serverClient.connected()){
    if(serverClient.available()){
      //get data from the telnet client
      while(serverClient.available()){
          serverClient.read();
      }
    }
  }*/

//Send data
  if (serverClient && serverClient.connected()){
    for(int i=0;i<p_telemetria;i++){
      for(int j=0;j<DIM_TELEMETRIA;j++){
        serverClient.print(telemetria[i][j]);
        serverClient.print(" ");
      }
      serverClient.println("");
    }
    serverClient.println("");
    p_telemetria=0;
    delay(5);
   }
  
}

void leerParedes(){
    uint8_t IR_value[3]={0};
    leerIRs(IR_value);
    
    
}

void setup() {
  // put your setup code here, to run once:
  delay(500);

  Serial.begin(115200);
  init_telnet();
  
  robot.begin();

   os_timer_setfn(&timerSpeedController, speedProfile, NULL);
   os_timer_arm(&timerSpeedController, 25, true);
   resetSpeedProfile();
}

#define TIME_BT_MOVE 10
int num_loop=1;
int dir=1;
void loop() {
  moveOneCell();
  delay(TIME_BT_MOVE);
  moveOneCell();
  delay(TIME_BT_MOVE);
  moveOneCell();
  delay(TIME_BT_MOVE);
  moveOneCell();
  delay(TIME_BT_MOVE);
  /*turn90(1);
  delay(TIME_BT_MOVE);
  turn90(1);
  delay(TIME_BT_MOVE);*/
 
  /*if((num_loop++)%3==0){
    targetSpeedX=0;
    delay(10000);
  }*/
  check_send_telnet_telemetry();
  //delay(2000);

  
  
  /*for(int i=0;i<p_telemetria;i++){
    for(int j=0;j<5;j++){
      Serial.print(telemetria[i][j]);
      Serial.print(" ");
    }
    Serial.println("");
  }*/
  //p_telemetria=0;
  
  
}

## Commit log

2016-04-13 initial commit. schematic
    [ESP_multi_board.kicad_pcb, ESP_multi_board.sch]
2016-04-16 Reg5Vto3.3V añadido como hoja jerarquica, añadido conector I2C externo, añadido resistencia ESP
    [ESP_multi_board.sch, reg5to3_3V.sch]
2016-04-17 incluido conectores I2C externos para el MPU6050\n modificado JUMPER1
    [ESP_multi_board.sch]
2016-04-17 modificado jumper1
    [ESP_multi_board.sch]
2016-04-17 resueltos probelams con duplicados y checkeado esquematico
    [ESP_multi_board.sch, reg5to3_3V.sch]
2016-04-17 intento de asginar huellas
    [ESP_multi_board.sch, reg5to3_3V.sch]
2016-04-17 nuevo componente diseñado L293DD, asignadas huellas
    [ESP_multi_board.sch, reg5to3_3V.sch]
2016-04-17 intento de hacer path
    [ESP_multi_board.kicad_pcb]
2016-04-17 pendiente de enrutar, TODO: incluir diodos baterias, meditar los jumpers
    [ESP_multi_board.dsn, ESP_multi_board.kicad_pcb, ESP_multi_board.sch]
2016-04-18 actualizaciones en CRM. TODO: cambiar L293DD por L298smd, cambiar para controlar ENs con pwm, y pines de direccion de motores desde el extensor de pines, eliminar jumpers, ajustar tamaño de las resis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
    [ESP_multi_board.kicad_pcb, ESP_multi_board.sch, reg5to3_3V.sch]
2016-04-18 incluido DAC 4canales MCP4728, modificados conexion de motores para hacer pwm en los enables
    [ESP_multi_board.sch, reg5to3_3V.sch]
2016-04-18 modificada huella del jumper, incluidos condensadores en la linea de 3.3v
    [ESP-12_Adapter_v1.0.sch, ESP_multi_board.kicad_pcb, ESP_multi_board.sch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]
2016-04-19 autorouting generado con freerouting
    [ESP_multi_board.dsn, ESP_multi_board.kicad_pcb, ESP_multi_board.sch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]
2016-04-19 cambio de posiciones en la placa
    [ESP_multi_board.dsn, ESP_multi_board.kicad_pcb, ESP_multi_board.sch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]
2016-04-27 versión quasifinal
    [ESP_multi_board.dsn, ESP_multi_board.kicad_pcb, ESP_multi_board.sch]
2016-04-27 vesion simplificada, sin jumper y sinconectar los pines de int
    [ESP_multi_board.kicad_pcb, _saved_ESP_multi_board.sch, _saved_reg5to3_3V.sch]
2016-04-27 cambio de posición ADC y L293DD
    [ESP_multi_board.kicad_pcb, ESP_multi_board.sch, _saved_ESP_multi_board.sch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]
2016-04-28 incluida version de la placa alargada 10x2.5 cm
    [ESP_multi_board.sch, ESP_multi_board_alargada.kicad_pcb, ESP_multi_board_cuadrada.kicad_pcb]
2016-04-28 cambios para hacer la version alargada mas compacta
    [ESP_multi_board_alargada.dsn]
2016-04-30 cambio a L298 con diodos
    [ESP_multi_board.sch, _saved_ESP_multi_board.sch]
2016-04-30 asignadas huellas diodos, provisionales
    [ESP_multi_board.sch]
2016-04-30 huellas diodos actualizadas
    [ESP_multi_board.kicad_pcb, ESP_multi_board.sch, _saved_ESP_multi_board.sch]
2016-05-01 organizacion directorio
    [ESP_multi_board.sch, _saved_ESP_multi_board.sch, reg5to3_3V.sch]
2016-05-01 limpieza repo
    [ESP-12_Adapter_v1.0.sch]
2016-05-01 nueva placa con hueco para motores integrado
    [ESP_multi_board.dsn, ESP_multi_board.kicad_pcb, ESP_multi_board.sch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]
2016-05-02 motores mas juntos en la PCB
    [ESP_multi_board.kicad_pcb]
2016-05-03 Actualizadas huellas de acuerdo a los componentes de Mouser
    [ESP_multi_board.dsn, ESP_multi_board.kicad_pcb, ESP_multi_board.sch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]
2016-05-12 placa actualizada
    [ESP_multi_board.kicad_pcb, ESP_multi_board.sch]
2016-05-13 placa final con doble agujeros (sin doble troquel)
    [ESP_multi_board.kicad_pcb]
2016-05-17 limpiada (dobles elementos) y con refeencias unicas
    [ESP_multi_board.dsn, ESP_multi_board.kicad_pcb]
2016-05-18 Cambios en el layout y rutado de las pistas de corriente
    [ESP_multi_board.kicad_pcb, ESP_multi_board.sch]
2016-05-18 Finalizado posible layout
    [ESP_multi_board.kicad_pcb, ESP_multi_board.sch]
2016-05-18 Añadido texto al silkscreen (autores, año y versión), y generados los ficheros Gerber
    [ESP_multi_board.kicad_pcb, ESP_multi_board.sch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]
2016-07-06 Labeled components with their values
    [ESP_multi_board.kicad_pcb]
2016-08-30 Libreria para controlar el chip MCP modificada para usar los pines SDA y SCL apropiados al ESP-12
2016-08-30 Codigos de ejemplos simples para probar la entrada y salida digital (MCP) y los motores (L293)
2016-08-31 Codigo de ejemplo de lectura de los pines analogicos, comunicacion con el chip MAX11605EEE+
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2016-09-04 dxf files
    [ESP_multi_board-Edge.Cuts.dxf, ESP_multi_board-F.Cu.dxf]
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2016-09-04 Added IR sensor support
    [ESP_multi_board-Edge.Cuts.dxf, ESP_multi_board-F.Cu.dxf, sensor_holder.scad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]
2016-09-04 Rounded corners design. Added license, picture & readme.
    [sensor_holder.scad, sensor_holder.stl]
2016-09-06 firmware update and test to use IR sensors
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2016-09-06 Ejemplo de lectura de los sensores IR, comentado el modo scand para leer los 3 en paralelo
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2016-09-16 speed controller with one IR error, wall follower
    [testSpeedControl.ino]
2016-09-18 modificaciones del control de velocidad y control de giro
    [simulacionGiro.xlsx]
2016-09-19 ajuste de magnitudes, tiempos y velocidad del giro (calculos en Excel)
    [simulacionGiro.xlsx]
2016-10-19 cambios seguir pared 19-oct
    [simulacionGiro.xlsx]
